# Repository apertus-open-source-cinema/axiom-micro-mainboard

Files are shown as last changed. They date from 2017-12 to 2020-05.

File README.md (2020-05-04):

# AXIOM micro (revision 2)
A cheap open source camera.

While deveolping code for the AXIOM Beta, we wanted to have a cheap, working development
platform.   
This lead to the creation of the AXIOM Micro, which
uses a FPGA SoC of the same family (Xilinx Zynq) but is imlemented using much lower
cost components. This leads to a highly reduced overall image quality, which is quite
bad for cinematography but not that important for Playing around and prototyping new ideas and concepts.

To reduce work, most parts of the software of the AXIOM Beta should be used. Only the bitstream
should be a custom development, that doesnt have to be upstreamed.

## Technical specs

### Image Sensor
* Not replacable 1/3" Image Sensor
* 2.2 × 2.2 µm Pixel size
* 12 F-Stops Dynamic range
* ~40dB SNR
* 2304 × 1296 pixel resolution
    * Full HD video with image stabilisation is possible!
    * 60fps theoretical sensor limit
* 12 bit RAW output

### Image Processing
* Zynq 7010 FPGA for image processing and controlling tasks
* onboard motion sensor
* onboard 4GB eMMC for firmware - the SD card slot could be used for recording
* USB 2.0 OTG & Gigabit Ethernet

### General
* AXIOM Beta compatible plugin module and shield slots
* ~ 150€ BOM cost  (see [octopart](https://octopart.com/bom-tool/HYQ6fs35))

## Developing
To develop the PCBs, simply clone this repository with 
```
git clone --recursive https://gitlab.com/anuejn/axiom-micro-hardware
```

Then simply use Kicad to edit the scematics and PCB.

```diff
- Warning!
- This Project uses submodules! when you clone without --recursive Kicad wont find some libraries!
```

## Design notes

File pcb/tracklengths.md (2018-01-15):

# Track lengths for LVDS on Z-Turn Lite

## To CCD

| Pin on Z-Turn | Length (mm) |
| --- | --- |
| IO_B34_LP8 | 34.364549 |
| IO_B34_LN8 | 34.3176606 |
| IO_B34_LP16 | 34.2911176 |
| IO_B34_LN16 | 34.2165686 |
| IO_B34_LN17 | 34.2408002 |
| IO_B34_LP18 | 34.2181688 |
| IO_B34_LP20 | 34.3285064 |
| IO_B34_LN20 | 34.2897714 |
| IO_B34_LP21 | 34.1846662 |
| IO_B34_LN21 | 34.221293 |

The longest trace is 34.364549mm, the shortest 34.1846662mm. This results in a deviation of 0.1798827mm.

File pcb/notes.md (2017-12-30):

# Connector:
On Z-turn Lite: BSH-060-01-L/F/C-D-A(-TR)

On CDC Board:

https://github.com/liubenyuan/kicad-xeit/blob/master/xeit.pretty/CONN_BTH-060-XX-X-D-A.kicad_mod

BTH-060-01-L/F/C-D(-A)

* (L= 10 µ" Light Gold  in Contact Area, Matte Tin on Tail)
* (F= 3 µ" Flash Selective Gold in Contact Area, Matte Tin on Tail)
* (C= 50 µ" Gold  in Contact Area, Matte Tin on Tail)
* (A= Alignment pins)

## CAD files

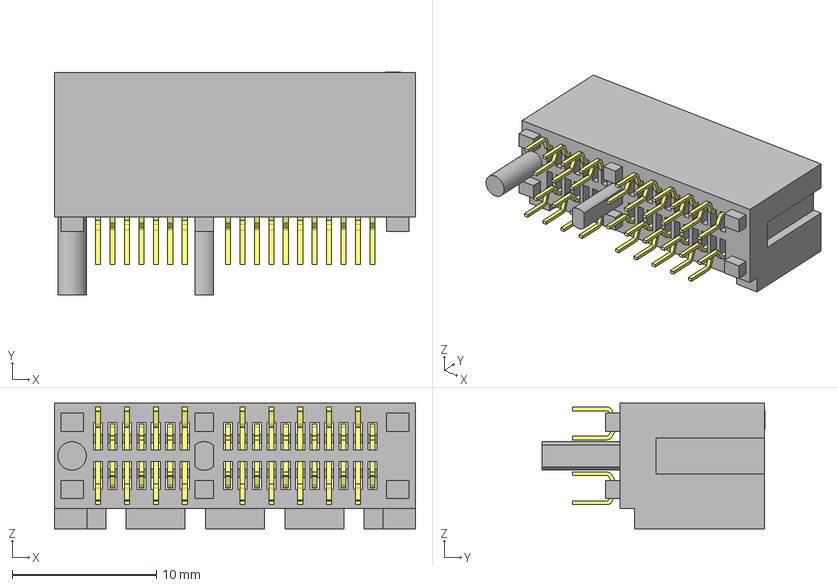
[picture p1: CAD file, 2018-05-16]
pcb/parts/3d/PCIE-036-02-S-D-TH.stp
25.0 x 15.4 x 8.70 mm
_PCIE-036-02-S-D-TH_body
_PCIE-036-02-S-D-TH_pins1
_PCIE-036-02-S-D-TH_pins2

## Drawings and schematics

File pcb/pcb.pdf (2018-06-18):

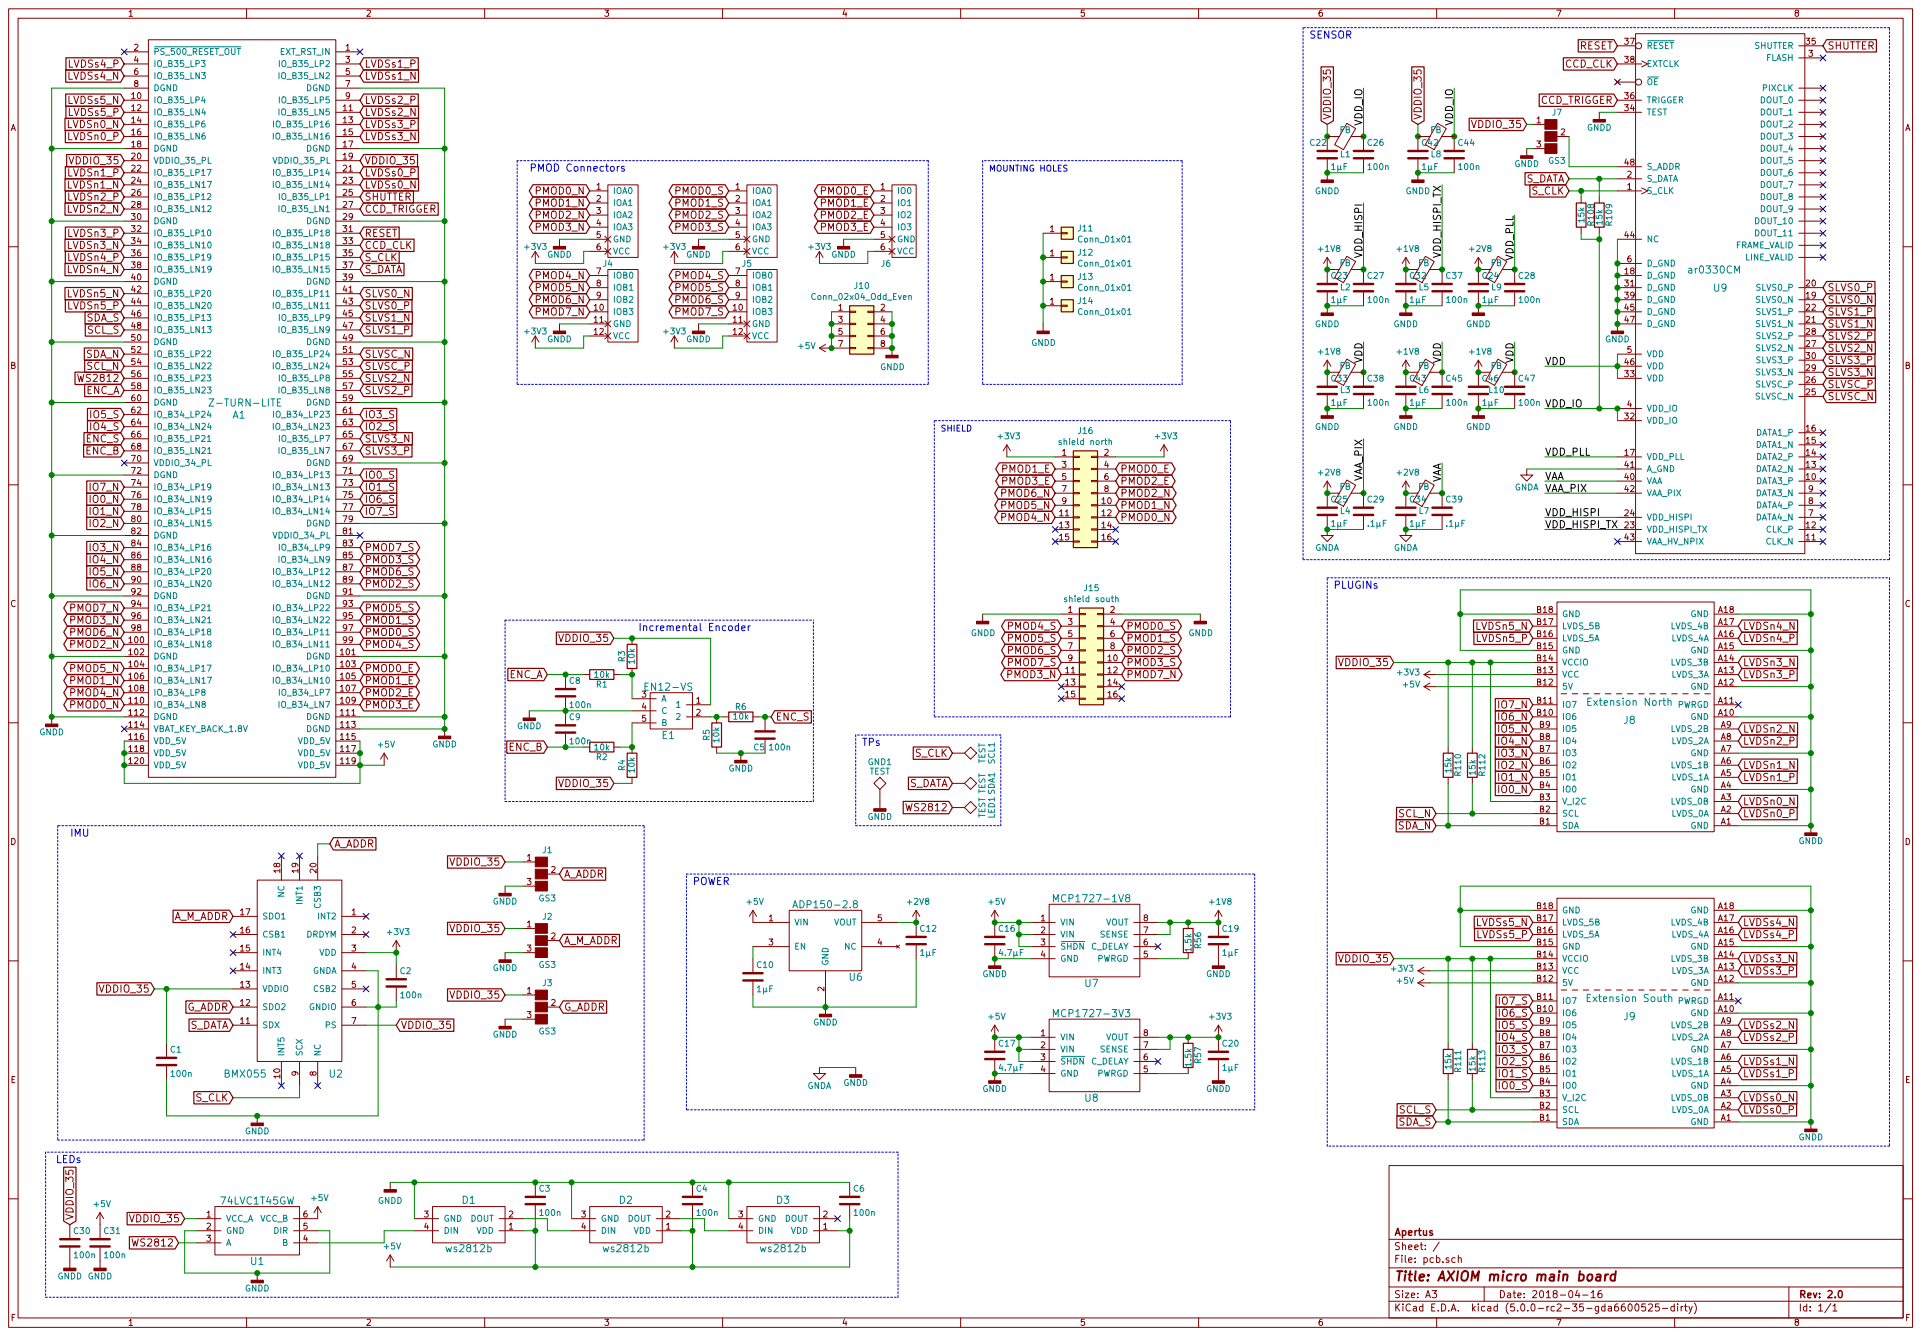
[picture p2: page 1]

File: pcb.sch Sheet: / Apertus

Id: 1/1 Title: AXIOM micro main board

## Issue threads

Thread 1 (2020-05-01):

r3 todo

rroohhh, 2020-05-01:
- [ ] figure out the usb pullup situation
- [ ] figure out if we want bulk decoupling for the sensor board on the mainboard (O(100uF))
- [ ] connect all the i2c stuff, add their addresses to the schematic, add the pullups, AN262_2 has some guidance on the pullup values
- [ ] connect the current / voltage sense ic's
  - [ ] figure out which resistors we want to use
- [ ] connect the ecp oscillator
  - [ ] decide if it should go to the RAM bank (or BANK 0), or BANK 8
- [ ] decide if we need a i2c gpio expander (we probably do atleast for the usb pullups)
  - [ ] what should go to the gpio expander, all the power supply enables, or ignore them, as we can set them via i2c
- [ ] figure out how to connect the 2 VBUS together
- [ ] figure out switcher frequency
- [ ] figure out switcher soft start capacitor
- [ ] figure out if we want to connect the i2c mux reset

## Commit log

2017-12-30 add information on board to board connectors
2017-12-30 add part file for connector
2017-12-30 add z-turn-lite kicad part
2017-12-30 add assets and start schematic
    [_saved_ccd_pcb.sch]
2017-12-30 do more scematics work
    [ccd_pcb.sch]
2017-12-30 add plugin module connector part
2017-12-30 add footprint for the pcie connector
2017-12-30 route power for plugin connector
    [ccd_pcb.sch]
2017-12-31 add LVDS connections to plugin connector
    [ccd_pcb.sch]
2018-01-01 add connections for the extention modules
    [ccd_pcb.sch]
2018-01-01 fix missing VCCIO on north extension port
    [ccd_pcb.sch]
2018-01-01 add mecanical documentation. Working on #4
    [pcb_stack.fcstd]
2018-01-01 Add component for shield connectors. Closes #3.
2018-01-02 fix pin types, clarify names
2018-01-03 add basic optical assembly
    [pcb_stack.fcstd]
2018-01-03 Add PMOD connectors
    [ccd_pcb.sch]
2018-01-03 update mechanical assembly
    [pcb_stack.fcstd]
2018-01-04 fix pin numbers on pmod
2018-01-04 track my fork of pmod until changes are merged
2018-01-04 fix minor bugs in the schematic
    [ccd_pcb.sch]
2018-01-05 correct the reference designators
    [ccd_pcb.sch]
2018-01-05 beautify schematic and add level shifter to pmod
    [ccd_pcb.sch]
2018-01-05 add bom
    [bom.csv]
2018-01-05 add component footprint mappings
    [ccd_pcb.sch]
2018-01-05 add track length overview
2018-01-06 add lvds terminating resistor (refer to #14)
    [ccd_pcb.sch]
2018-01-13 begin redoing mechanical design using solvespace
    [pcb_stack.fcstd]
2018-01-15 add more capacitors. closes #20
    [ccd_pcb.sch]
2018-01-15 begin layouting and routhing the board
    [ccd_pcb.kicad_pcb, ccd_pcb.sch]
2018-01-17 redo layout
    [ccd_pcb.kicad_pcb, ccd_pcb.sch]
2018-01-18 most of the routing done
    [ccd_pcb.kicad_pcb, ccd_pcb.sch]
2018-01-18 done routing; length matching and via stitching not done yet
    [ccd_pcb.kicad_pcb]
2018-01-19 almost finished
    [ccd_pcb.kicad_pcb]
2018-01-19 closes #21;
    [ccd_pcb.kicad_pcb, ccd_pcb.sch]
2018-01-19 minor improvments
    [ccd_pcb.kicad_pcb]
2018-01-19 some minor bugfixes
    [ccd_pcb-B.Cu.gbr, ccd_pcb-B.Mask.gbr, ccd_pcb-B.SilkS.gbr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]
2018-04-16 begin working on schematic v2
    [ccd_pcb.sch]
2018-04-17 v2 r1
    [ccd_pcb.sch]
2018-04-17 add incremental encoder and soldering training
    [ccd_pcb.sch]
2018-04-17 small fix
    [ccd_pcb.sch]
2018-04-17 more stuff
    [ccd_pcb.kicad_pcb, ccd_pcb.sch]
2018-04-18 better model of zturn lite
    [ccd_pcb.kicad_pcb]
2018-04-30 schematic and board design
    [ccd_pcb-B.Cu.gbr, ccd_pcb-B.Mask.gbr, ccd_pcb-B.SilkS.gbr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]
2018-04-30 modify pathname
    [ccd_pcb-B.Cu.gbr, ccd_pcb-B.Mask.gbr, ccd_pcb-B.SilkS.gbr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]
2018-04-30 add schematic as pdf
    [pcb.sch]
2018-05-13 first routing pass done
    [pcb.kicad_pcb, pcb.sch]
2018-05-13 improve some routing
    [pcb.kicad_pcb, pcb.sch]
2018-05-14 optimize silkscreen
    [pcb.kicad_pcb]
2018-05-14 optimize hf layout
    [pcb.kicad_pcb]
2018-05-14 add meanders
    [pcb.kicad_pcb]
2018-05-14 finishing touches
    [pcb.kicad_pcb, pcb.sch]
2018-05-14 add pdf of schematic
    [pcb.kicad_pcb]
2018-05-14 remove outdated gerbers; those files should be attached to the releases, as they are build artifacts
    [ccd_pcb-B.Cu.gbr, ccd_pcb-B.Mask.gbr, ccd_pcb-B.SilkS.gbr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]
2018-05-15 minor tweaks
    [pcb.kicad_pcb]
2018-05-15 reduce padsize of bmx055
    [pcb.kicad_pcb]
2018-05-16 make traces thinner; optimize qfn and clcc layout
    [pcb.kicad_pcb]
2018-05-16 remove bottom silkscreen from pmod
    [pcb.kicad_pcb, pcb.sch]
2018-05-16 minor optimisations
    [pcb.kicad_pcb]
2018-05-16 add 3d
    [pcb.kicad_pcb]
2018-05-16 add 3d model of connectors
    [PCIE-036-02-S-D-TH.stp, pcb.kicad_pcb]
2018-05-20 add scuffed shield
    [pcb.kicad_pcb, pcb.sch]
2018-05-20 exclude gerbers
2018-05-20 switch north and south shield connector
    [pcb.kicad_pcb, pcb.sch]
2018-05-20 place shields and begin routing
    [pcb.kicad_pcb]
2018-05-21 fix placement of shield connectors
    [pcb.kicad_pcb]
2018-05-21 add routing proposal
    [pcb.kicad_pcb]
2018-05-21 finish shields
    [pcb.kicad_pcb, pcb.sch]
2018-05-21 remove ground fill around sensor
    [pcb.kicad_pcb]
2018-05-21 finish and optimize routing of shield connector
    [pcb.kicad_pcb]
2018-05-21 fix shield orientation
    [pcb.kicad_pcb, pcb.sch]
2018-05-24 add oshw logo and fiduicals
    [pcb.kicad_pcb]
2018-06-29 clean repo
    [bom.csv]
